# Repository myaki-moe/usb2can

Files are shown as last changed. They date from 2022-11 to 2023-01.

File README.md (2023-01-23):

# USB2CAN

USB2CAN is a compact and low cost open source USB to CAN bus adaptor. 

Based on candleLight firmware and STM32F072 crystal-less MCU, usb2can provides linux native socketcan support.

USB2CAN是一款紧凑且低成本的开源USB到CAN总线转化器.

基于candleLight固件和STM32F072无外置晶振MCU, usb2can提供了Linux原生SocketCAN支持.

## Quick Start | 快速开始

1. PCB proofing using GERBER file `usb2can_pcb/gerber/`
2. SMD or hand soldering using [ibom](usb2can_pcb/bom/ibom.html)
3. Build candleLight firmware
4. Flash the firmware using `dfu-utils`
5. Testing
```bash
sudo ip link set can0 up type can bitrate 1000000
# CAN receive
candump can0
# CAN send
cansend can0 200#5A5A5A5A5A5A5A5A
```

1. 使用GERBER文件 `usb2can_pcb/gerber/` 打样PCB
2. SMT或使用 [ibom](usb2can_pcb/bom/ibom.html)手工焊接
3. 编译candleLight固件
4. 使用 `dfu-utils` 烧录固件
5. 测试
```bash
sudo ip link set can0 up type can bitrate 1000000
# CAN receive
candump can0
# CAN send
cansend can0 200#5A5A5A5A5A5A5A5A
```

## Toolchains | 工具链

* PCB Design: KiCad 6.0.9
* Complier: arm-none-eabi-gcc 12.2.0
* Firmware Programmer: dfu-utils 0.11

* PCB设计: KiCad 6.0.9
* 编译器: arm-none-eabi-gcc 12.2.0
* 固件烧录: dfu-utils 0.11

## License | 许可证

* The USB2CAN project is released under GPLv3 license.

* candleLight Firmware Sources is distributed under the MIT License (MIT) Copyright (c) 2016 Hubert Denkmair

* The STM32 HAL is distributed under a non-restrictive BSD (Berkeley Software Distribution) license.

* Code from the STM32 USB library is licensed under ST STMicroelectronics [Ultimate Liberty license SLA0044](www.st.com/SLA0044)

* USB2CAN项目基于GPLv3协议发布

* candleLight固件源码根据MIT分发, 版权所有2016 Hubert Denkmair

* STM32 HAL 在非限制性BSD许可下分发.

* STM32 USB 库中的代码根据 [Ultimate Liberty license SLA0044](www.st.com/SLA0044) 获得许可

## Related Projects | 相关项目

[candleLight_fw](https://github.com/candle-usb/candleLight_fw)

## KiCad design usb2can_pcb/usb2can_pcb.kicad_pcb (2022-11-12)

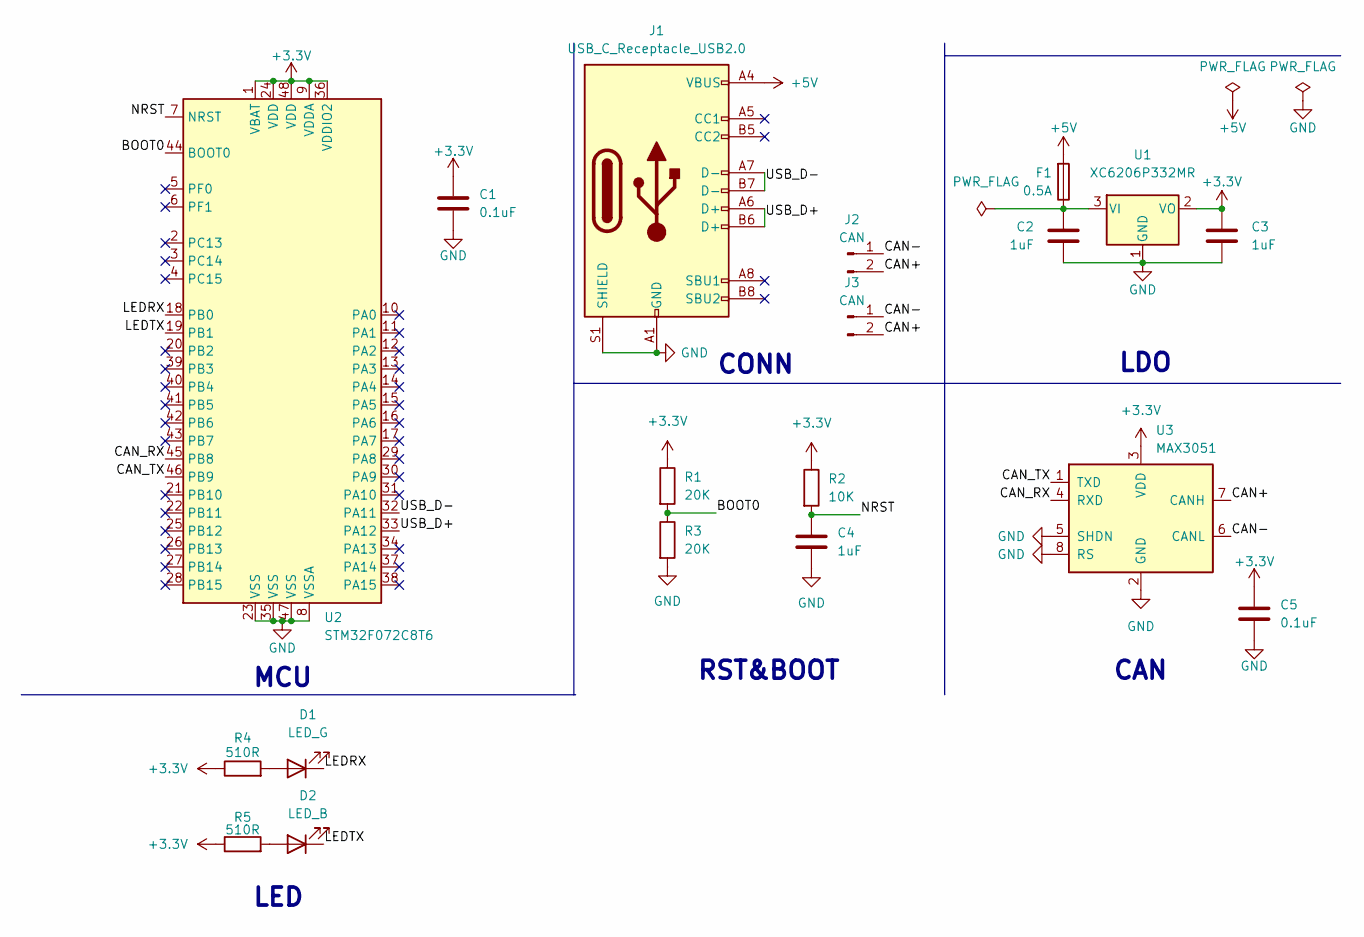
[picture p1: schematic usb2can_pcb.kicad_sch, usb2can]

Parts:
C1, C5: 0.1uF; C_0402_1005Metric
C2, C3, C4: 1uF; C_0402_1005Metric
D1: LED_G; D_0402_1005Metric
D2: LED_B; D_0402_1005Metric
F1: 0.5A; Fuse_0603_1608Metric
J1: USB_C_Receptacle_USB2.0; USB_C_Receptacle_Palconn_UTC16-G
J2, J3: CAN; JST_GH_SM02B-GHS-TB_1x02-1MP_P1.25mm_Horizontal
R1, R3: 20K; R_0402_1005Metric
R2: 10K; R_0402_1005Metric
R4, R5: 510R; R_0402_1005Metric
U1: XC6206P332MR; SOT-23
U2: STM32F072C8T6; LQFP-48_7x7mm_P0.5mm
U3: MAX3051; SOT-23-8

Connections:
+3.3V: C1.1, C3.1, C5.1, R1.1, R2.1, R4.1, R5.1, U1.2 (VO), U2.1 (VBAT), U2.9 (VDDA), U2.24 (VDD), U2.36 (VDDIO2), U2.48 (VDD), U3.3 (VDD)
+5V: F1.2, J1.A4 (VBUS), J1.A9 (VBUS), J1.B4 (VBUS), J1.B9 (VBUS)
/BOOT0: R1.2, R3.1, U2.44 (BOOT0)
/CAN+: J2.2, J3.2, U3.7 (CANH)
/CAN-: J2.1, J3.1, U3.6 (CANL)
/CAN_RX: U2.45 (PB8), U3.4 (RXD)
/CAN_TX: U2.46 (PB9), U3.1 (TXD)
/LEDRX: D1.1 (K), U2.18 (PB0)
/LEDTX: D2.1 (K), U2.19 (PB1)
/NRST: C4.1, R2.2, U2.7 (NRST)
/USB_D+: J1.A6 (D+), J1.B6 (D+), U2.33 (PA12)
/USB_D-: J1.A7 (D-), J1.B7 (D-), U2.32 (PA11)
GND: C1.2, C2.1, C3.2, C4.2, C5.2, J1.A1 (GND), J1.A12 (GND), J1.B1 (GND), J1.B12 (GND), J1.S1 (SHIELD), R3.2, U1.1 (GND), U2.8 (VSSA), U2.23 (VSS), U2.35 (VSS), U2.47 (VSS), U3.2 (GND), U3.5 (SHDN), U3.8 (RS)
unnamed: C2.2, F1.1, U1.3 (VI)
unnamed: D1.2 (A), R4.2
unnamed: D2.2 (A), R5.2

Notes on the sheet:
LED
RST&BOOT
CONN
CAN
LDO
MCU

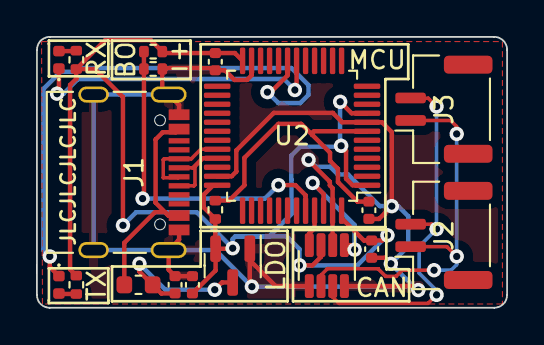
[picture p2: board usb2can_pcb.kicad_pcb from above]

Board: 2 copper layers, 26.1 x 15.0 mm, 19 parts (0 on the bottom side), 16 nets.

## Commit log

2022-11-02 add pcb design 1.0
    [usb2can_pcb.kicad_pcb, usb2can_pcb.kicad_sch]
2022-11-02 add customer number placeholder for JLCPCB
    [usb2can_pcb.kicad_pcb]
2022-11-02 generate GERBER
    [usb2can_pcb-B_Cu.gbr, usb2can_pcb-B_Mask.gbr, usb2can_pcb-B_Paste.gbr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]
2022-11-09 Generate interactive BOM
2022-11-10 fix CAN connector pin assign problem
    [usb2can_pcb-B_Cu.gbr, usb2can_pcb-B_Mask.gbr, usb2can_pcb-B_Paste.gbr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]
2022-11-12 fix sch version display error
    [usb2can_pcb.kicad_sch]
2022-11-12 fix pcb version display error
    [usb2can_pcb.kicad_pcb]
